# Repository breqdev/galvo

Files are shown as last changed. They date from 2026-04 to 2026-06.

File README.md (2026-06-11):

# Laser Vector Projector

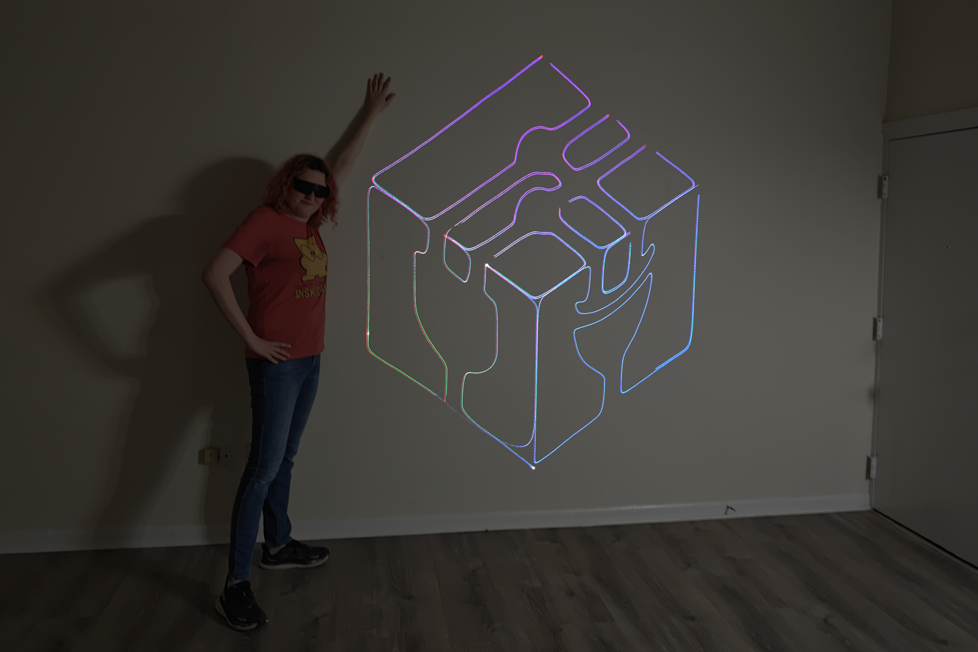
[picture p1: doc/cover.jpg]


Read the project writeup [here](https://breq.dev/projects/laser-projector)!

> This project is sponsored by PCBWay, who generously provided PCB fabrication services for this project. PCBWay provides high-quality boards with fast turnaround at low cost, and are a great option for both hobbyists and professionals.

Contained in this repository:

- [KiCAD Board Layout Files](board)
- [Bill of Materials](board/ESP32%20Galvo%20Driver.csv)
- [Firmware](galvo-firmware) -- you'll need to have the [Espressif toolchain](https://docs.espressif.com/projects/rust/book/getting-started/toolchain.html) installed to compile this
- [CAD files](cad) (SketchUp source files and STL)

Stuff not covered in the Bill of Materials:

- [RGB laser module and driver](https://www.aliexpress.us/item/3256810125144918.html)
- [Galvos with XY mount, driver, and power supply](https://www.aliexpress.us/item/3256809659931894.html)
- [Laser safety goggles](https://lasersafety.com/product/f42-p5l13-5000/)

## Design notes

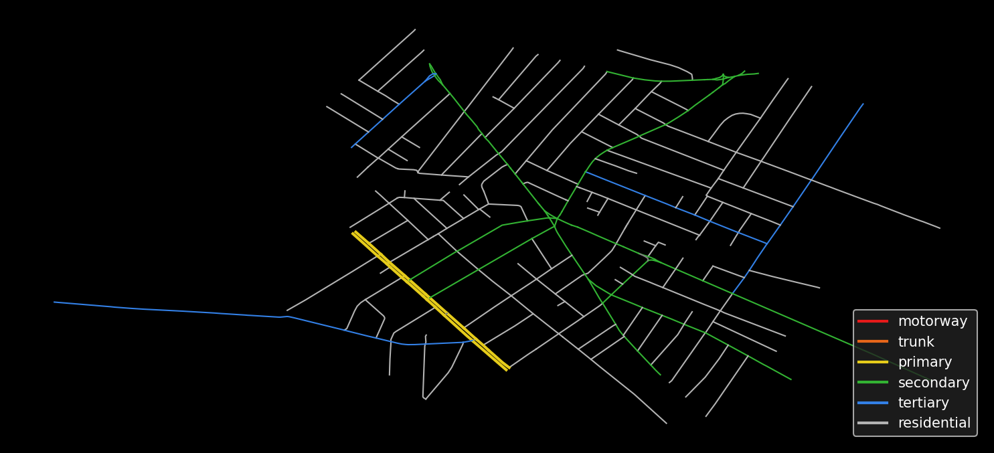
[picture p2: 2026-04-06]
scripts/roads.png

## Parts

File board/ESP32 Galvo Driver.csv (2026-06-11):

Reference | Value | Footprint | Datasheet | Qty | DNP | Exclude from BOM | Exclude from Board
C1,C4,C7,C8,C10 | 10uF | Capacitor_SMD:C_0603_1608Metric_Pad1.08x0.95mm_HandSolder |  | 5
C2,C3,C9,C11 | 0.1uF | Capacitor_SMD:C_0603_1608Metric_Pad1.08x0.95mm_HandSolder |  | 4
C5 | 100nF | Capacitor_SMD:C_0603_1608Metric_Pad1.08x0.95mm_HandSolder |  | 1
C6 | 47uF | Capacitor_SMD:C_0603_1608Metric_Pad1.08x0.95mm_HandSolder |  | 1
D1,D2,D3,D4 | 10V | Diode_SMD:D_SOD-123 |  | 4
F1 | Fuse | Fuse:Fuseholder_Clip-5x20mm_Littelfuse_111_Inline_P20.00x5.00mm_D1.05mm_Horizontal |  | 1
J1 | 15V Power In | Connector_Molex:Molex_KK-254_AE-6410-03A_1x03_P2.54mm_Vertical |  | 1
J2 | RED | Connector_JST:JST_XH_B2B-XH-A_1x02_P2.50mm_Vertical |  | 1
J3 | GREEN | Connector_JST:JST_XH_B2B-XH-A_1x02_P2.50mm_Vertical |  | 1
J4 | BLUE | Connector_JST:JST_XH_B2B-XH-A_1x02_P2.50mm_Vertical |  | 1
J5 | Native USB | Connector_USB:USB_C_Receptacle_GCT_USB4105-xx-A_16P_TopMnt_Horizontal | https://www.usb.org/sites/default/files/documents/usb_type-c.zip | 1
J6 | Galvo X Output | Connector_JST:JST_XH_B3B-XH-A_1x03_P2.50mm_Vertical |  | 1
J7 | Galvo Y Output | Connector_JST:JST_XH_B3B-XH-A_1x03_P2.50mm_Vertical |  | 1
J8 | Debug USB | Connector_USB:USB_C_Receptacle_GCT_USB4105-xx-A_16P_TopMnt_Horizontal | https://www.usb.org/sites/default/files/documents/usb_type-c.zip | 1
J9 | IEC_60320_C14_Receptacle | ESP32 Galvo Driver:QUALTEK_703W-00_52 |  | 1
J10 | 15V Supply In | Connector_Molex:Molex_KK-396_5273-05A_1x05_P3.96mm_Vertical |  | 1
J11 | AudioJack3_SwitchTR | Connector_Audio:Jack_3.5mm_CUI_SJ1-3525N_Horizontal |  | 1
J12 | LASER_EN | Connector_JST:JST_XH_B2B-XH-A_1x02_P2.50mm_Vertical |  | 1
J13 | FAN | Connector_JST:JST_XH_B2B-XH-A_1x02_P2.50mm_Vertical |  | 1
J14 | Laser Key | Connector_JST:JST_XH_B2B-XH-A_1x02_P2.50mm_Vertical |  | 1
J15 | Conn_01x05 | Connector_PinHeader_2.54mm:PinHeader_1x05_P2.54mm_Vertical |  | 1
J16 | Quiic 1 | Connector_JST:JST_SH_BM04B-SRSS-TB_1x04-1MP_P1.00mm_Vertical |  | 1
J17 | Quiic 2 | Connector_JST:JST_SH_BM04B-SRSS-TB_1x04-1MP_P1.00mm_Vertical |  | 1
L1 | 3.3uH | Inductor_SMD:L_0805_2012Metric_Pad1.15x1.40mm_HandSolder |  | 1
P1 | Wii 1 | ESP32 Galvo Driver:Nintendo_Wii_Peripheral_5Pin_Card_edge | https://bootlin.com/labs/doc/nunchuk.pdf | 1
P2 | Wii 2 | ESP32 Galvo Driver:Nintendo_Wii_Peripheral_5Pin_Card_edge | https://bootlin.com/labs/doc/nunchuk.pdf | 1
PS1 | IRM-05-12 | Converter_ACDC:Converter_ACDC_MeanWell_IRM-05-xx_THT | https://www.meanwell.com/Upload/PDF/IRM-05/IRM-05-SPEC.PDF | 1
Q1,Q2,Q4 | NPN | Package_TO_SOT_SMD:SOT-23-3 | https://ngspice.sourceforge.io/docs/ngspice-html-manual/manual.xhtml#cha_BJTs | 3
Q3 | AO3401A | Package_TO_SOT_SMD:SOT-23 | http://www.aosmd.com/pdfs/datasheet/AO3401A.pdf | 1
R1 | 1K | Resistor_SMD:R_0603_1608Metric_Pad0.98x0.95mm_HandSolder |  | 1
R2,R3 | 10K | Resistor_SMD:R_0603_1608Metric_Pad0.98x0.95mm_HandSolder |  | 2
R4,R5 | 470 | Resistor_SMD:R_0603_1608Metric_Pad0.98x0.95mm_HandSolder |  | 2
R6 | 22.1k | Resistor_SMD:R_0603_1608Metric_Pad0.98x0.95mm_HandSolder |  | 1
R7 | 47.5k | Resistor_SMD:R_0603_1608Metric_Pad0.98x0.95mm_HandSolder |  | 1
R8,R12,R15,R20 | 150k | Resistor_SMD:R_0603_1608Metric_Pad0.98x0.95mm_HandSolder |  | 4
R9,R13,R17,R19 | 12k | Resistor_SMD:R_0603_1608Metric_Pad0.98x0.95mm_HandSolder |  | 4
R10,R16 | 9.1k | Resistor_SMD:R_0603_1608Metric_Pad0.98x0.95mm_HandSolder |  | 2
R11,R18,R23,R32,R33,R34,R35 | 10k | Resistor_SMD:R_0603_1608Metric_Pad0.98x0.95mm_HandSolder |  | 7
R14,R21,R25 | 1k | Resistor_SMD:R_0603_1608Metric_Pad0.98x0.95mm_HandSolder |  | 3
R22 | 33.2k | Resistor_SMD:R_0603_1608Metric_Pad0.98x0.95mm_HandSolder |  | 1
R24 | 2.2k | Resistor_SMD:R_0603_1608Metric_Pad0.98x0.95mm_HandSolder |  | 1
R26,R27,R28,R29 | 5.1k | Resistor_SMD:R_0603_1608Metric_Pad0.98x0.95mm_HandSolder |  | 4
R30 | 100k | Resistor_SMD:R_0603_1608Metric_Pad0.98x0.95mm_HandSolder |  | 1
R31 | 27k | Resistor_SMD:R_0603_1608Metric_Pad0.98x0.95mm_HandSolder |  | 1
RV3 | 1k | Potentiometer_THT:Potentiometer_Alps_RK163_Dual_Horizontal |  | 1
SW1 | BOOT | Button_Switch_THT:SW_Tactile_SPST_Angled_PTS645Vx58-2LFS |  | 1
SW2 | RESET | Button_Switch_THT:SW_Tactile_SPST_Angled_PTS645Vx58-2LFS |  | 1
TP1 | 12V | TestPoint:TestPoint_Pad_D2.5mm |  | 1
TP2 | 3.3V | TestPoint:TestPoint_Pad_D2.5mm |  | 1
U1 | ESP32-S2-SOLO | PCM_Espressif:ESP32-S2-SOLO | https://www.espressif.com/sites/default/files/documentation/esp32-s2-solo_esp32-s2-solo-u_datasheet_en.pdf | 1
U2 | CP2102N-Axx-xQFN28 | Package_DFN_QFN:QFN-28-1EP_5x5mm_P0.5mm_EP3.35x3.35mm | https://www.silabs.com/documents/public/data-sheets/cp2102n-datasheet.pdf | 1
U3 | TL084 | Package_SO:SOIC-14_3.9x8.7mm_P1.27mm | http://www.ti.com/lit/ds/symlink/tl081.pdf | 1
U4 |  | Package_TO_SOT_SMD:SOT-23-6_Handsoldering |  | 1
U5 | MCP4922-ESL | Package_SO:SOIC-14_3.9x8.7mm_P1.27mm | http://ww1.microchip.com/downloads/en/devicedoc/21897a.pdf | 1

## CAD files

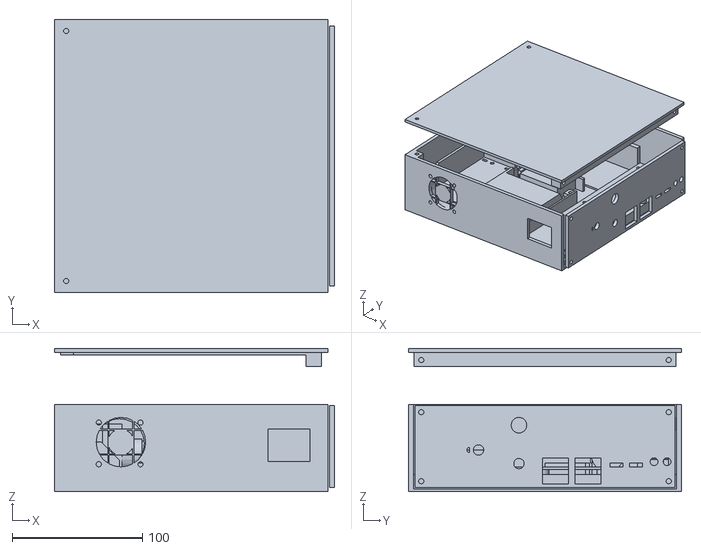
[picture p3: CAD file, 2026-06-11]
cad/RGB Galvo Enclosure.stl
215.0 x 210.0 x 110.0

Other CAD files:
cad/RGB Galvo Enclosure.skp

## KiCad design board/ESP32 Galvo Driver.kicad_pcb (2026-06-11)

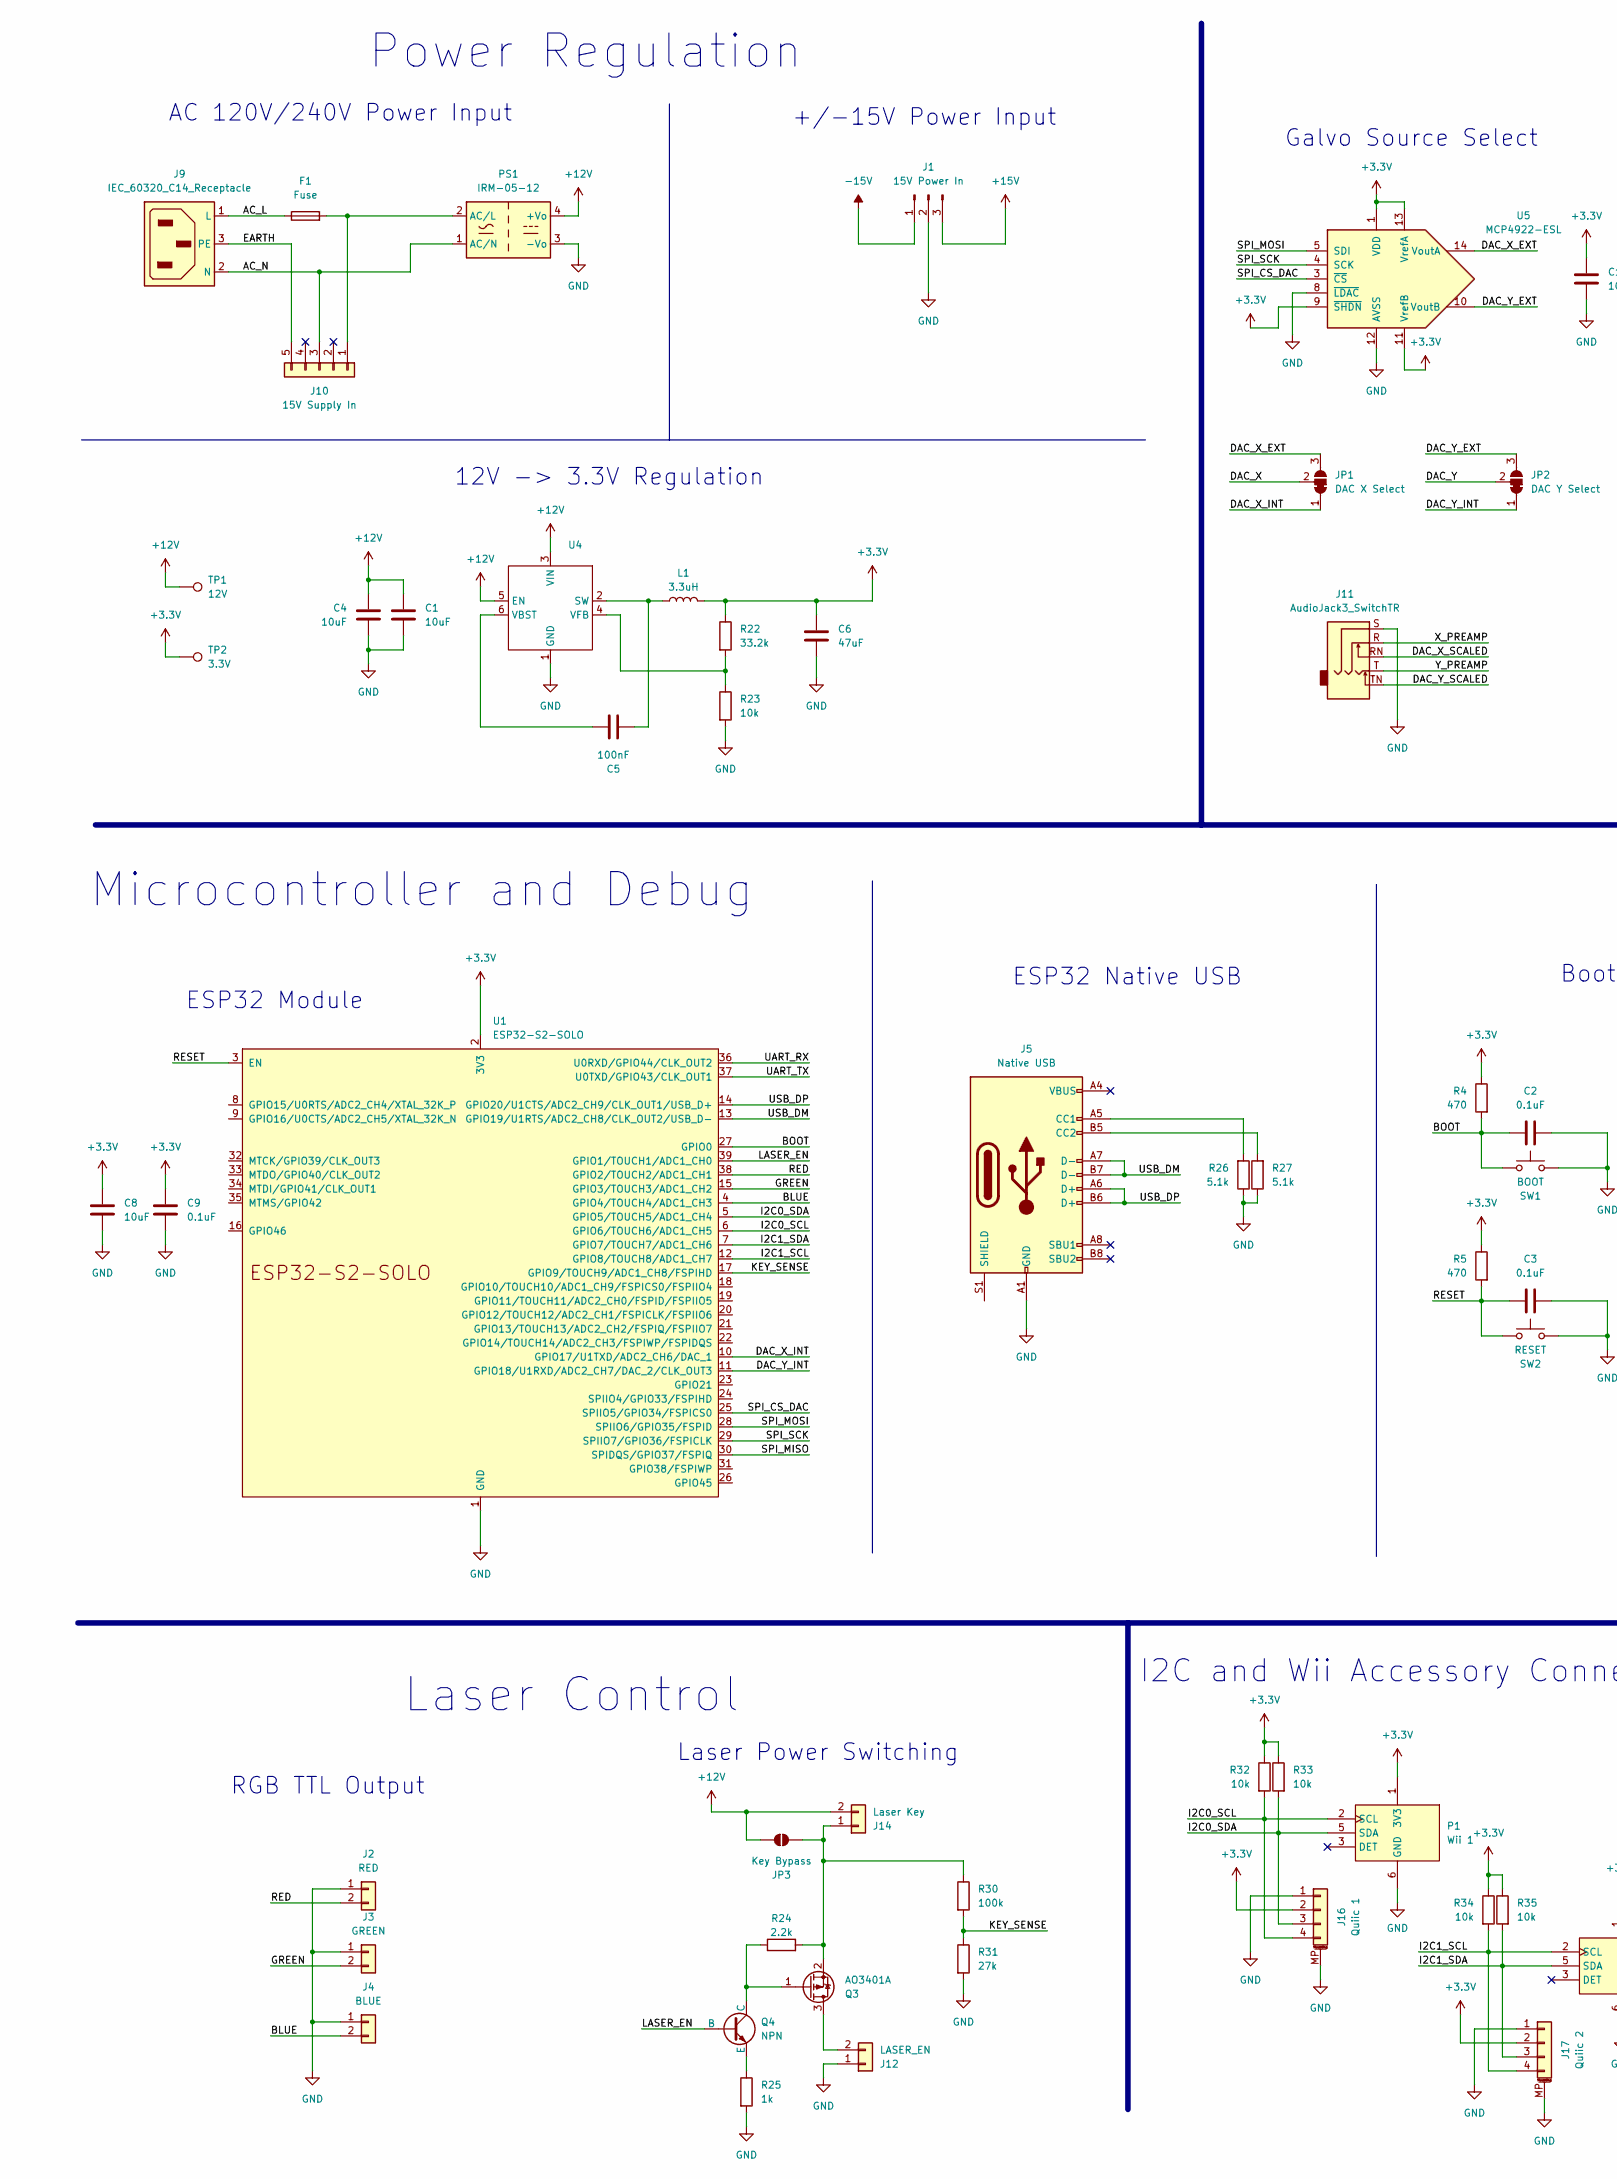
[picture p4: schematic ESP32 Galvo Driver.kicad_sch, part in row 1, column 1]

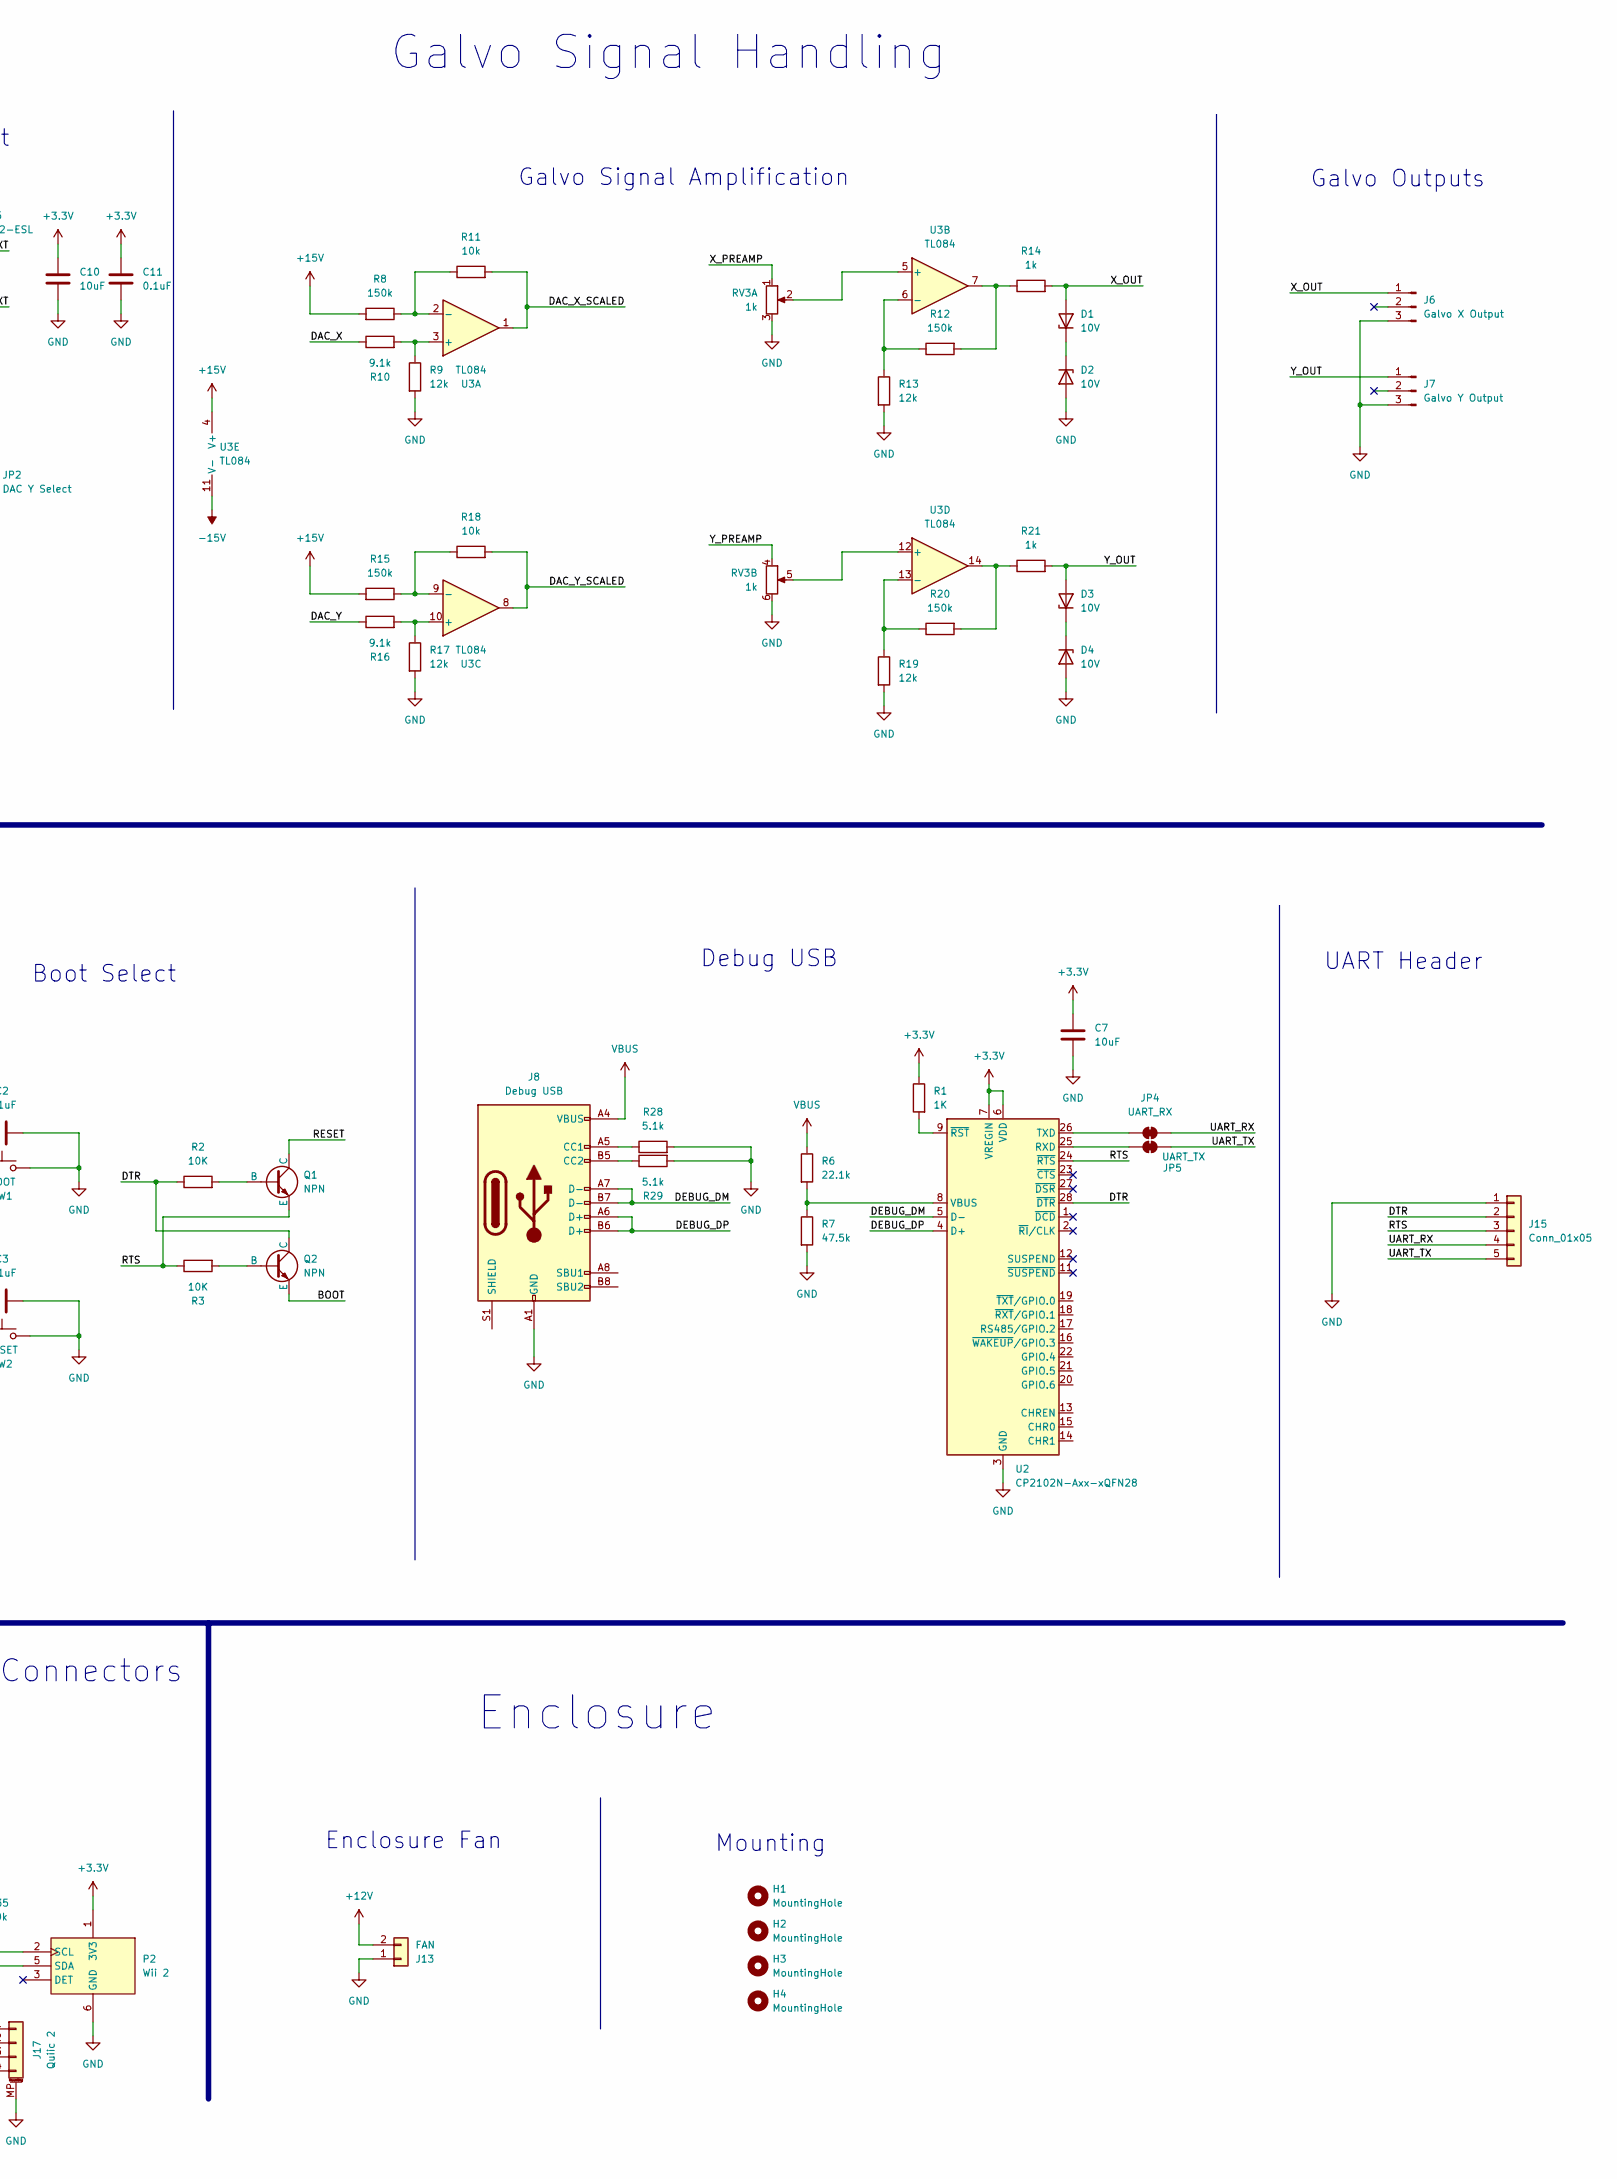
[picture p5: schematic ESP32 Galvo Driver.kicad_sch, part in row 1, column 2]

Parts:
C1, C4, C7, C8, C10: 10uF; C_0603_1608Metric_Pad1.08x0.95mm_HandSolder
C2, C3, C9, C11: 0.1uF; C_0603_1608Metric_Pad1.08x0.95mm_HandSolder
C5: 100nF; C_0603_1608Metric_Pad1.08x0.95mm_HandSolder
C6: 47uF; C_0603_1608Metric_Pad1.08x0.95mm_HandSolder
D1, D2, D3, D4: 10V; D_SOD-123
F1: Fuse; Fuseholder_Clip-5x20mm_Littelfuse_111_Inline_P20.00x5.00mm_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
H1, H2, H3, H4: MountingHole; MountingHole_3.2mm_M3
J1: 15V Power In; Molex_KK-254_AE-6410-03A_1x03_P2.54mm_Vertical
J2: RED; JST_XH_B2B-XH-A_1x02_P2.50mm_Vertical
J3: GREEN; JST_XH_B2B-XH-A_1x02_P2.50mm_Vertical
J4: BLUE; JST_XH_B2B-XH-A_1x02_P2.50mm_Vertical
J5: Native USB; USB_C_Receptacle_GCT_USB4105-xx-A_16P_TopMnt_Horizontal
J6: Galvo X Output; JST_XH_B3B-XH-A_1x03_P2.50mm_Vertical
J7: Galvo Y Output; JST_XH_B3B-XH-A_1x03_P2.50mm_Vertical
J8: Debug USB; USB_C_Receptacle_GCT_USB4105-xx-A_16P_TopMnt_Horizontal
J9: IEC_60320_C14_Receptacle; QUALTEK_703W-00_52
J10: 15V Supply In; Molex_KK-396_5273-05A_1x05_P3.96mm_Vertical
J11: AudioJack3_SwitchTR; Jack_3.5mm_CUI_SJ1-3525N_Horizontal
J12: LASER_EN; JST_XH_B2B-XH-A_1x02_P2.50mm_Vertical
J13: FAN; JST_XH_B2B-XH-A_1x02_P2.50mm_Vertical
J14: Laser Key; JST_XH_B2B-XH-A_1x02_P2.50mm_Vertical
J15: Conn_01x05; PinHeader_1x05_P2.54mm_Vertical
J16: Quiic 1; JST_SH_BM04B-SRSS-TB_1x04-1MP_P1.00mm_Vertical
J17: Quiic 2; JST_SH_BM04B-SRSS-TB_1x04-1MP_P1.00mm_Vertical
JP1: DAC X Select; SolderJumper-3_P1.3mm_Bridged12_RoundedPad1.0x1.5mm
JP2: DAC Y Select; SolderJumper-3_P1.3mm_Bridged12_RoundedPad1.0x1.5mm
JP3: Key Bypass; SolderJumper-2_P1.3mm_Open_TrianglePad1.0x1.5mm
JP4: UART_RX; SolderJumper-2_P1.3mm_Bridged_Pad1.0x1.5mm
JP5: UART_TX; SolderJumper-2_P1.3mm_Bridged_Pad1.0x1.5mm
L1: 3.3uH; L_0805_2012Metric_Pad1.15x1.40mm_HandSolder
P1: Wii 1; Nintendo_Wii_Peripheral_5Pin_Card_edge
P2: Wii 2; Nintendo_Wii_Peripheral_5Pin_Card_edge
PS1: IRM-05-12; Converter_ACDC_MeanWell_IRM-05-xx_THT
Q1, Q2, Q4: NPN; SOT-23-3
Q3: AO3401A; SOT-23
R1: 1K; R_0603_1608Metric_Pad0.98x0.95mm_HandSolder
R2, R3: 10K; R_0603_1608Metric_Pad0.98x0.95mm_HandSolder
R4, R5: 470; R_0603_1608Metric_Pad0.98x0.95mm_HandSolder
R6: 22.1k; R_0603_1608Metric_Pad0.98x0.95mm_HandSolder
R7: 47.5k; R_0603_1608Metric_Pad0.98x0.95mm_HandSolder
R8, R12, R15, R20: 150k; R_0603_1608Metric_Pad0.98x0.95mm_HandSolder
R9, R13, R17, R19: 12k; R_0603_1608Metric_Pad0.98x0.95mm_HandSolder
R10, R16: 9.1k; R_0603_1608Metric_Pad0.98x0.95mm_HandSolder
R11, R18, R23, R32, R33, R34, R35: 10k; R_0603_1608Metric_Pad0.98x0.95mm_HandSolder
R14, R21, R25: 1k; R_0603_1608Metric_Pad0.98x0.95mm_HandSolder
R22: 33.2k; R_0603_1608Metric_Pad0.98x0.95mm_HandSolder
R24: 2.2k; R_0603_1608Metric_Pad0.98x0.95mm_HandSolder
R26, R27, R28, R29: 5.1k; R_0603_1608Metric_Pad0.98x0.95mm_HandSolder
R30: 100k; R_0603_1608Metric_Pad0.98x0.95mm_HandSolder
R31: 27k; R_0603_1608Metric_Pad0.98x0.95mm_HandSolder
RV3: 1k; Potentiometer_Alps_RK163_Dual_Horizontal
SW1: BOOT; SW_Tactile_SPST_Angled_PTS645Vx58-2LFS
SW2: RESET; SW_Tactile_SPST_Angled_PTS645Vx58-2LFS
TP1: 12V; TestPoint_Pad_D2.5mm
TP2: 3.3V; TestPoint_Pad_D2.5mm
U1: ESP32-S2-SOLO
U2: CP2102N-Axx-xQFN28; QFN-28-1EP_5x5mm_P0.5mm_EP3.35x3.35mm
U3: TL084; SOIC-14_3.9x8.7mm_P1.27mm
U4: SOT-23-6_Handsoldering
U5: MCP4922-ESL; SOIC-14_3.9x8.7mm_P1.27mm

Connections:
+3.3V: C6.1, C7.1, C8.1, C9.1, C10.1, C11.1, J16.2, J17.2, L1.2, P1.1 (3V3), P2.1 (3V3), R1.1, R4.1, R5.1, R22.1, R32.1, R33.1, R34.1, R35.1, TP2.1 (1_1), U1.2 (3V3), U2.6 (VDD), U2.7 (VREGIN), U5.1 (VDD), U5.9 (~SHDN), U5.11 (VrefB), U5.13 (VrefA)
+12V: C1.1, C4.1, J13.2, J14.2, JP3.1 (A), PS1.4 (+Vo), TP1.1 (1_1), U4.3 (VIN), U4.5 (EN)
+15V: J1.3, R8.2, R15.2, U3.4 (V+)
-15V: J1.1, U3.11 (V-)
/AC_L: F1.1, J9.1 (L)
/AC_N: J9.2 (N), J10.3, PS1.1 (AC/N)
/BLUE: J4.2, U1.4 (GPIO4/TOUCH4/ADC1_CH3)
/BOOT: C2.1, Q2.3 (E), R4.2, SW1.2, U1.27 (GPIO0)
/DAC_X: JP1.2 (C), R10.1
/DAC_X_EXT: JP1.3 (B), U5.14 (VoutA)
/DAC_X_INT: JP1.1 (A), U1.10 (GPIO17/U1TXD/ADC2_CH6/DAC_1)
/DAC_X_SCALED: J11.RN, R11.2, U3.1
/DAC_Y: JP2.2 (C), R16.1
/DAC_Y_EXT: JP2.3 (B), U5.10 (VoutB)
/DAC_Y_INT: JP2.1 (A), U1.11 (GPIO18/U1RXD/ADC2_CH7/DAC_2/CLK_OUT3)
/DAC_Y_SCALED: J11.TN, R18.2, U3.8
/DEBUG_DM: J8.A7 (D-), J8.B7 (D-), U2.5 (D-)
/DEBUG_DP: J8.A6 (D+), J8.B6 (D+), U2.4 (D+)
/DTR: J15.2, Q2.1 (C), R2.1, U2.28 (~DTR)
/EARTH: J9.3 (PE), J10.5
/GREEN: J3.2, U1.15 (GPIO3/TOUCH3/ADC1_CH2)
/I2C0_SCL: J16.4, P1.2 (SCL), R32.2, U1.6 (GPIO6/TOUCH6/ADC1_CH5)
/I2C0_SDA: J16.3, P1.5 (SDA), R33.2, U1.5 (GPIO5/TOUCH5/ADC1_CH4)
/I2C1_SCL: J17.4, P2.2 (SCL), R34.2, U1.12 (GPIO8/TOUCH8/ADC1_CH7)
/I2C1_SDA: J17.3, P2.5 (SDA), R35.2, U1.7 (GPIO7/TOUCH7/ADC1_CH6)
/KEY_SENSE: R30.2, R31.1, U1.17 (GPIO9/TOUCH9/ADC1_CH8/FSPIHD)
/LASER_EN: Q4.2 (B), U1.39 (GPIO1/TOUCH1/ADC1_CH0)
/RED: J2.2, U1.38 (GPIO2/TOUCH2/ADC1_CH1)
/RESET: C3.1, Q1.1 (C), R5.2, SW2.2, U1.3 (EN)
/RTS: J15.3, Q1.3 (E), R3.1, U2.24 (~RTS)
/SPI_CS_DAC: U1.25 (SPIIO5/GPIO34/FSPICS0), U5.3 (~CS)
/SPI_MISO: U1.30 (SPIDQS/GPIO37/FSPIQ)
/SPI_MOSI: U1.28 (SPIIO6/GPIO35/FSPID), U5.5 (SDI)
/SPI_SCK: U1.29 (SPIIO7/GPIO36/FSPICLK), U5.4 (SCK)
/UART_RX: J15.4, JP4.2 (B), U1.36 (U0RXD/GPIO44/CLK_OUT2)
/UART_TX: J15.5, JP5.2 (B), U1.37 (U0TXD/GPIO43/CLK_OUT1)
/USB_DM: J5.A7 (D-), J5.B7 (D-), U1.13 (GPIO19/U1RTS/ADC2_CH8/CLK_OUT2/USB_D-)
/USB_DP: J5.A6 (D+), J5.B6 (D+), U1.14 (GPIO20/U1CTS/ADC2_CH9/CLK_OUT1/USB_D+)
/X_OUT: D1.2 (A), J6.1, R14.2
/X_PREAMP: J11.R, RV3.1
/Y_OUT: D3.2 (A), J7.1, R21.2
/Y_PREAMP: J11.T, RV3.4
GND: C1.2, C2.2, C3.2, C4.2, C6.2, C7.2, C8.2, C9.2, C10.2, C11.2, D2.2 (A), D4.2 (A), J1.2, J2.1, J3.1, J4.1, J5.A1 (GND), J5.A12 (GND), J5.B1 (GND), J5.B12 (GND), J6.3, J7.3, J8.A1 (GND), J8.A12 (GND), J8.B1 (GND), J8.B12 (GND), J11.S, J12.1, J13.1, J15.1, J16.1, J16.MP (MountPin), J17.1, J17.MP (MountPin), P1.6 (GND), P2.6 (GND), PS1.3 (-Vo), R7.2, R9.2, R13.2, R17.2, R19.2, R23.2, R25.2, R26.1, R27.1, R28.2, R29.2, R31.2, RV3.3, RV3.6, SW1.1, SW2.1, U1.1 (GND), U1.40 (GND), U1.41 (GND), U2.3 (GND), U2.29 (GND), U4.1 (GND), U5.8 (~LDAC), U5.12 (AVSS)
unnamed: D1.1 (K), D2.1 (K)
unnamed: D3.1 (K), D4.1 (K)
unnamed: J5.A5 (CC1), R26.2
unnamed: J5.B5 (CC2), R27.2
unnamed: J8.A5 (CC1), R28.1
unnamed: J8.B5 (CC2), R29.1
unnamed: F1.2, J10.1, PS1.2 (AC/L)
unnamed: J12.2, Q3.3 (D)
unnamed: J14.1, JP3.2 (B), Q3.2 (S), R24.2, R30.1
unnamed: JP4.1 (A), U2.26 (TXD)
unnamed: JP5.1 (A), U2.25 (RXD)
unnamed: Q1.2 (B), R2.2
unnamed: Q2.2 (B), R3.2
unnamed: Q3.1 (G), Q4.1 (C), R24.1
unnamed: Q4.3 (E), R25.1
unnamed: R12.2, R14.1, U3.7
unnamed: R20.2, R21.1, U3.14
unnamed: R6.2, R7.1, U2.8 (VBUS)
unnamed: R1.2, U2.9 (~RST)
unnamed: R9.1, R10.2, U3.3 (+)
unnamed: R8.1, R11.1, U3.2 (-)
unnamed: RV3.2, U3.5 (+)
unnamed: R12.1, R13.1, U3.6 (-)
unnamed: R16.2, R17.1, U3.10 (+)
unnamed: R15.1, R18.1, U3.9 (-)
unnamed: RV3.5, U3.12 (+)
unnamed: R19.1, R20.1, U3.13 (-)
unnamed: C5.2, L1.1, U4.2 (SW)
unnamed: C5.1, U4.6 (VBST)
unnamed: R22.2, R23.1, U4.4 (VFB)
VBUS: J8.A4 (VBUS), J8.A9 (VBUS), J8.B4 (VBUS), J8.B9 (VBUS), R6.1

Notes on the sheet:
Power Regulation
Enclosure
ESP32 Native USB
Microcontroller and Debug
AC 120V/240V Power Input
12V -> 3.3V Regulation
UART Header
RGB TTL Output
Laser Power Switching
Galvo Signal Handling
Boot Select
ESP32 Module
Enclosure Fan
I2C and Wii Accessory Connectors
Mounting
Laser Control
Galvo Source Select
+/-15V Power Input
Debug USB
Galvo Signal Amplification
Galvo Outputs

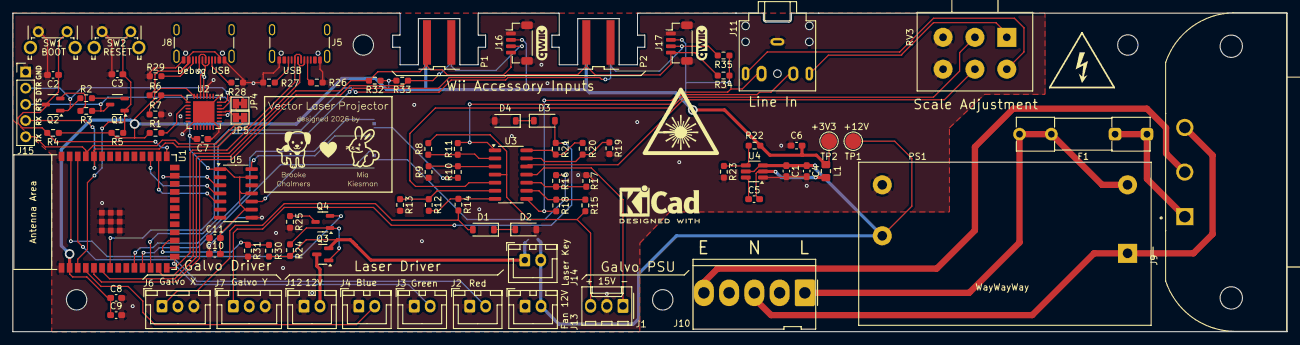
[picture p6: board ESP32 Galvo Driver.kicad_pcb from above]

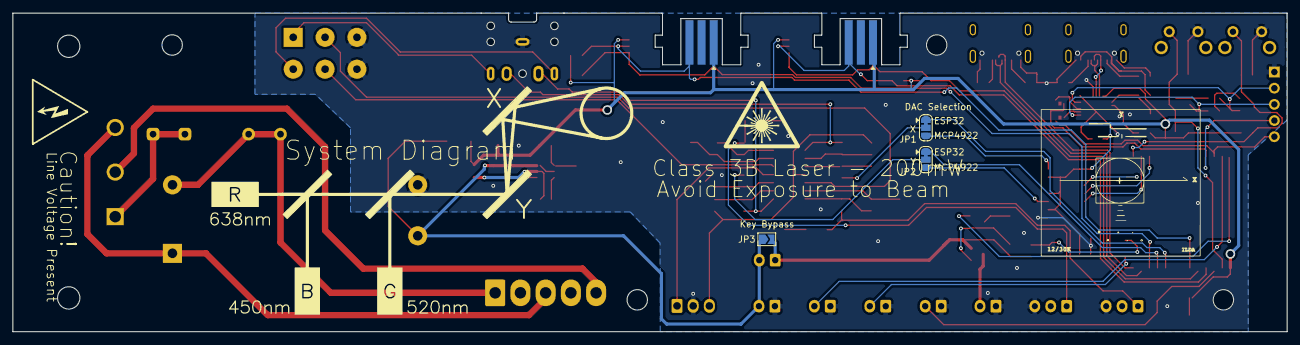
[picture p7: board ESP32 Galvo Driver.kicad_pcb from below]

Board: 2 copper layers, 200.0 x 50.0 mm, 95 parts (3 on the bottom side), 73 nets.

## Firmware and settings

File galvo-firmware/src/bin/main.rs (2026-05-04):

#![no_std]
#![no_main]
#![deny(
    clippy::mem_forget,
    reason = "mem::forget is generally not safe to do with esp_hal types, especially those \
    holding buffers for the duration of a data transfer."
)]

use alloc::boxed::Box;
use alloc::string::String;
use alloc::vec::Vec;
use embassy_executor::Spawner;
use embassy_net::{DhcpConfig, StackResources};
use embassy_time::{Duration, Timer};
use esp_backtrace as _;
use esp_hal::clock::CpuClock;
use esp_hal::delay::Delay;
use esp_hal::i2c::master::{Config, I2c};
use esp_hal::ledc::timer::TimerIFace;
use esp_hal::ledc::{Ledc, LowSpeed, timer};
use esp_hal::otg_fs::{Usb, UsbBus};
use esp_hal::peripherals;
use esp_hal::rng::Rng;
use esp_hal::rtc_cntl::Rtc;
use esp_hal::time::Rate;
use esp_hal::timer::timg::TimerGroup;
use esp_radio::Controller;
use galvo_driver::controls::parse_report;
use galvo_driver::network::{
    RtcTimeSource, SharedRtc, connection, get_mastodon_status, get_time_ntp, net_task,
};
use galvo_driver::protocol::{Command, Response};
use usb_device::prelude::{UsbDeviceBuilder, UsbVidPid};
use usbd_serial::{SerialPort, USB_CLASS_CDC};
use vector_apps::apps::clock::Clock;
use vector_apps::apps::svg::SvgApp;
use vector_apps::apps::{self, Controls, VectorApp};
use wii_accessories::WiiAccessory;

use log::info;

use embassy_sync::blocking_mutex::Mutex;
use galvo_driver::lasers::Lasers;
use galvo_driver::led::IndicatorLed;
use vector_apps::apps::align::Align;
use vector_apps::apps::alphabet::AlphabetDemo;
use vector_apps::apps::asteroids::Asteroids;
use vector_apps::apps::cube::CubeDemo;
use vector_apps::apps::cycle::Cycle;
use vector_apps::apps::ilda::Ilda;
use vector_apps::apps::maps::Maps;

extern crate alloc;

// This creates a default app-descriptor required by the esp-idf bootloader.
// For more information see: <https://docs.espressif.com/projects/esp-idf/en/stable/esp32/api-reference/system/app_image_format.html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>
esp_bootloader_esp_idf::esp_app_desc!();

// When you are okay with using a nightly compiler it's better to use https://docs.rs/static_cell/2.1.0/static_cell/macro.make_static.html
macro_rules! mk_static {
    ($t:ty,$val:expr) => {{
        static STATIC_CELL: static_cell::StaticCell<$t> = static_cell::StaticCell::new();
        #[deny(unused_attributes)]
        let x = STATIC_CELL.uninit().write(($val));
        x
    }};
}

static mut EP_MEMORY: [u32; 1024] = [0; 1024];

#[esp_rtos::main]
async fn main(spawner: Spawner) -> ! {
    // generator version: 1.0.1

    esp_println::logger::init_logger_from_env();

    let config = esp_hal::Config::default().with_cpu_clock(CpuClock::max());
    let peripherals = esp_hal::init(config);

    esp_alloc::heap_allocator!(#[esp_hal::ram(reclaimed)] size: 139264);

    let timg0 = TimerGroup::new(peripherals.TIMG0);
    esp_rtos::start(timg0.timer0);

    info!("Embassy initialized!");

    let delay = Delay::new();

    let ledc = Ledc::new(peripherals.LEDC);
    let mut timer = ledc.timer::<LowSpeed>(timer::Number::Timer0);
    timer
        .configure(timer::config::Config {
            duty: timer::config::Duty::Duty8Bit,
            clock_source: timer::LSClockSource::APBClk,
            frequency: Rate::from_khz(24),
        })
        .unwrap();

    let mut lasers = Lasers::new(
        peripherals.GPIO1,
        peripherals.GPIO9,
        peripherals.GPIO2,
        peripherals.GPIO3,
        peripherals.GPIO4,
        ledc,
        &timer,
        peripherals.DAC2,
        peripherals.GPIO18,
        peripherals.DAC1,
        peripherals.GPIO17,
    );

    let mut controls_p1 = {
        let i2c = I2c::new(peripherals.I2C0, Config::default())
            .unwrap()
            .with_sda(peripherals.GPIO5)
            .with_scl(peripherals.GPIO6);

        WiiAccessory::new(i2c)
    };
    let mut controls_p2 = {
        let i2c = I2c::new(peripherals.I2C1, Config::default())
            .unwrap()
            .with_sda(peripherals.GPIO7)
            .with_scl(peripherals.GPIO8);

        WiiAccessory::new(i2c)
    };

    let usb = Usb::new(peripherals.USB0, peripherals.GPIO20, peripherals.GPIO19);
    let usb_bus = UsbBus::new(usb, unsafe { &mut *core::ptr::addr_of_mut!(EP_MEMORY) });

    let mut serial = SerialPort::new(&usb_bus);

    let mut usb_dev = UsbDeviceBuilder::new(&usb_bus, UsbVidPid(0x303A, 0x3001))
        .device_class(USB_CLASS_CDC)
        .build();

    let rtc = mk_static!(SharedRtc, Mutex::new(Rtc::new(peripherals.LPWR)));

    let esp_radio_ctrl = &*mk_static!(Controller<'static>, esp_radio::init().unwrap());

    let (controller, interfaces) =
        esp_radio::wifi::new(esp_radio_ctrl, peripherals.WIFI, Default::default()).unwrap();

    let wifi_interface = interfaces.sta;

    let mut dhcp_options: DhcpConfig = Default::default();
    dhcp_options.hostname = Some(heapless::String::try_from("laser-esp32").unwrap());
    let config = embassy_net::Config::dhcpv4(dhcp_options);

    let rng = Rng::new();
    let seed = (rng.random() as u64) << 32 | rng.random() as u64;

    // Init network stack
    let (stack, runner) = embassy_net::new(
        wifi_interface,
        config,
        mk_static!(StackResources<8>, StackResources::<8>::new()),
        seed,
    );

    spawner.spawn(connection(controller)).ok();
    spawner.spawn(net_task(runner)).ok();

    info!("Waiting for network...");

    stack.wait_config_up().await;

    // get_time_ntp(&stack, rtc).await;

    // let post = get_mastodon_status(&stack).await;

    let mut serial_buffer: [u8; 2048] = [0; 2048];
    let mut serial_rx_length: usize = 0;

    let mut apps: Vec<Box<dyn VectorApp>> = Vec::with_capacity(5);
    apps.push(Box::new(AlphabetDemo::new(String::from(
        "Hershey Goth Engbreq.dev",
        // "  KiCad  NewStroke breq.dev",
    ))));
    // apps.push(Box::new(CubeDemo::new()));
    // apps.push(Box::new(Asteroids::new()));
    // apps.push(Box::new(Maps::new()));
    // apps.push(Box::new(SvgApp::new()));
    // apps.push(Box::new(Ilda::new()));
    apps.push(Box::new(Align::new()));
    // apps.push(Box::new(Clock::new(RtcTimeSource::new(rtc))));

    let mut active_demo: Box<dyn apps::VectorApp> = Box::new(Cycle::new(apps));
    // let mut active_demo: Box<dyn apps::VectorApp> = Box::new(Asteroids::new());

    let mut frameno: u64 = 0;

    info!("Galvo system initialized!");

    loop {
        if usb_dev.poll(&mut [&mut serial]) {
            let mut buf = [0u8; 64];

            if let Ok(count) = serial.read(&mut buf)
                && count > 0
            {
                // Append to RX buffer
                if serial_rx_length + count <= serial_buffer.len() {
                    serial_buffer[serial_rx_length..serial_rx_length + count]
                        .copy_from_slice(&buf[..count]);
                    serial_rx_length += count;
                }

                // Look for newline delimiter
                if let Some(pos) = serial_buffer[..serial_rx_length]
                    .iter()
                    .position(|&b| b == b'\n')
                {
                    let json_bytes = &serial_buffer[..pos];

                    if let Ok(s) = core::str::from_utf8(json_bytes)
                        && let Ok(cmd) = serde_json::from_str::<Command>(s)
                    {
                        match cmd {
                            Command::SetIndicatorLight { r, g, b } => {
                                // indicator.set_color(smart_leds::RGB { r, g, b });
                            }
                        }

                        let result = Response { success: true };

                        let response = serde_json::to_string(&result).unwrap();
                        let _ = serial.write(response.as_bytes());
                    }

                    // Remove processed message
                    let remaining = serial_rx_length - (pos + 1);
                    serial_buffer.copy_within(pos + 1..serial_rx_length, 0);
                    serial_rx_length = remaining;
                }
            }
        }

        // if lasers.is_interlock_active() {
        //     info!("Key in ON position");
        // } else {
        //     info!("Key in OFF position");
        // }

        if frameno % 4 == 0 {
            let player_1 = parse_report(controls_p1.get_input());
            let player_2 = parse_report(controls_p2.get_input());
            // info!("controls state: {:?}", controls);
            let merged = player_1.merge(player_2);
            active_demo.handle_controls(merged);
        }

        frameno += 1;

        for p in active_demo.get_path(frameno) {
            // Output coordinates
            lasers.display(p);

            // DAC/galvo settling time
            delay.delay_micros(p.delay as u32);
        }

        // yield to other tasks
        Timer::after(Duration::from_millis(1)).await;
    }
}

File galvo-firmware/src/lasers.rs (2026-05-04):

use esp_hal::analog::dac::Dac;
use esp_hal::gpio::interconnect::PeripheralOutput;
use esp_hal::gpio::{
    DriveMode, Input, InputConfig, InputPin, Level, Output, OutputConfig, OutputPin,
};
use esp_hal::ledc::channel::{Channel, ChannelHW, ChannelIFace};
use esp_hal::ledc::timer::Timer;
use esp_hal::ledc::{LSGlobalClkSource, Ledc, LowSpeed, channel};
use esp_hal::peripherals::{DAC1, DAC2, GPIO17, GPIO18};

use vector_apps::point::Point;

pub struct Lasers<'a> {
    enable: Output<'a>,
    interlock: Input<'a>,
    red: Channel<'a, LowSpeed>,
    green: Channel<'a, LowSpeed>,
    blue: Channel<'a, LowSpeed>,
    x: Dac<'a, DAC2<'a>>,
    y: Dac<'a, DAC1<'a>>,
}

impl<'a> Lasers<'a> {
    pub fn new(
        enable: impl OutputPin + 'a,
        interlock: impl InputPin + 'a,
        red: impl PeripheralOutput<'a>,
        green: impl PeripheralOutput<'a>,
        blue: impl PeripheralOutput<'a>,
        mut ledc: Ledc<'a>,
        timer: &'a Timer<'a, LowSpeed>,
        dac_x: DAC2<'a>,
        pin_x: GPIO18<'a>,
        dac_y: DAC1<'a>,
        pin_y: GPIO17<'a>,
    ) -> Self {
        ledc.set_global_slow_clock(LSGlobalClkSource::APBClk);

        let en_output = Output::new(enable, Level::Low, OutputConfig::default());
        let interlock_input = Input::new(interlock, InputConfig::default());

        let mut red_ch = ledc.channel(channel::Number::Channel0, red);
        red_ch
            .configure(channel::config::Config {
                timer,
                duty_pct: 10,
                drive_mode: DriveMode::PushPull,
            })
            .unwrap();

        let mut green_ch = ledc.channel(channel::Number::Channel1, green);
        green_ch
            .configure(channel::config::Config {
                timer,
                duty_pct: 10,
                drive_mode: DriveMode::PushPull,
            })
            .unwrap();

        let mut blue_ch = ledc.channel(channel::Number::Channel2, blue);
        blue_ch
            .configure(channel::config::Config {
                timer,
                duty_pct: 10,
                drive_mode: DriveMode::PushPull,
            })
            .unwrap();

        Self {
            enable: en_output,
            interlock: interlock_input,
            red: red_ch,
            green: green_ch,
            blue: blue_ch,
            x: Dac::new(dac_x, pin_x),
            y: Dac::new(dac_y, pin_y),
        }
    }

    pub fn is_interlock_active(&self) -> bool {
        self.interlock.is_high()
    }

    pub fn display(&mut self, p: &Point) {
        self.enable.set_high();

        self.x.write(255 - p.x);
        self.y.write(255 - p.y);
        self.red.set_duty_hw(p.color.0 as u32);
        self.green.set_duty_hw(p.color.1 as u32);
        self.blue.set_duty_hw(p.color.2 as u32);
    }
}

impl<'a> Drop for Lasers<'a> {
    fn drop(&mut self) {
        self.enable.set_low();
    }
}

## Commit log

2026-02-08 add board!
    [ESP32 Galvo Driver.kicad_pcb, ESP32 Galvo Driver.kicad_sch]
2026-02-13 ILDA test pattern WIP
    [ESP32 Galvo Driver.kicad_pcb, ESP32 Galvo Driver.kicad_sch]
2026-02-14 update board
    [ESP32 Galvo Driver.kicad_pcb, ESP32 Galvo Driver.kicad_sch]
2026-02-21 gtfs, litt.chr parsing
    [ESP32 Galvo Driver.kicad_pcb, ESP32 Galvo Driver.kicad_sch]
2026-03-14 switch to pinouts from PCB, separate package for vector text
    [ESP32 Galvo Driver.kicad_pcb, ESP32 Galvo Driver.kicad_sch]
2026-03-15 move wii accessory driver to separate crate
2026-06-11 board updates: fix improper wiring of AC input
    [ESP32 Galvo Driver.kicad_pcb, ESP32 Galvo Driver.kicad_sch]
2026-06-11 add BOM
    [ESP32 Galvo Driver.csv]
2026-06-11 import CAD and add readme
    [RGB Galvo Enclosure.skp, RGB Galvo Enclosure.stl]
